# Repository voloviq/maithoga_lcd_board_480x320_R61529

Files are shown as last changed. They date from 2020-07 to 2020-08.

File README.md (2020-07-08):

# maithoga_lcd_board_480x320_R61529
PCB Board for Maithoga display with resolution 480x320 based on chip R61529 compatible with ILI9481.

Access to display signal is possible with goldpin described below and fpc compatible with LicheePi Zero board.

Display view

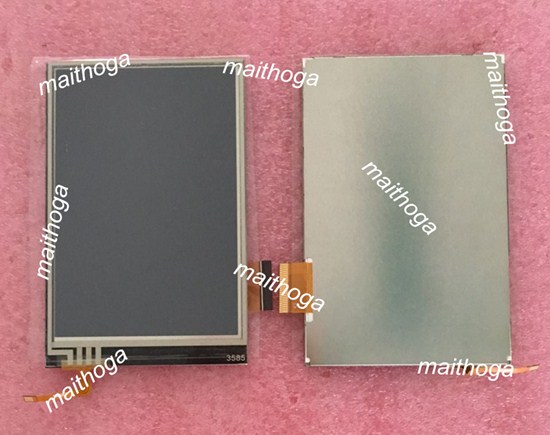
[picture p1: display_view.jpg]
Display_View


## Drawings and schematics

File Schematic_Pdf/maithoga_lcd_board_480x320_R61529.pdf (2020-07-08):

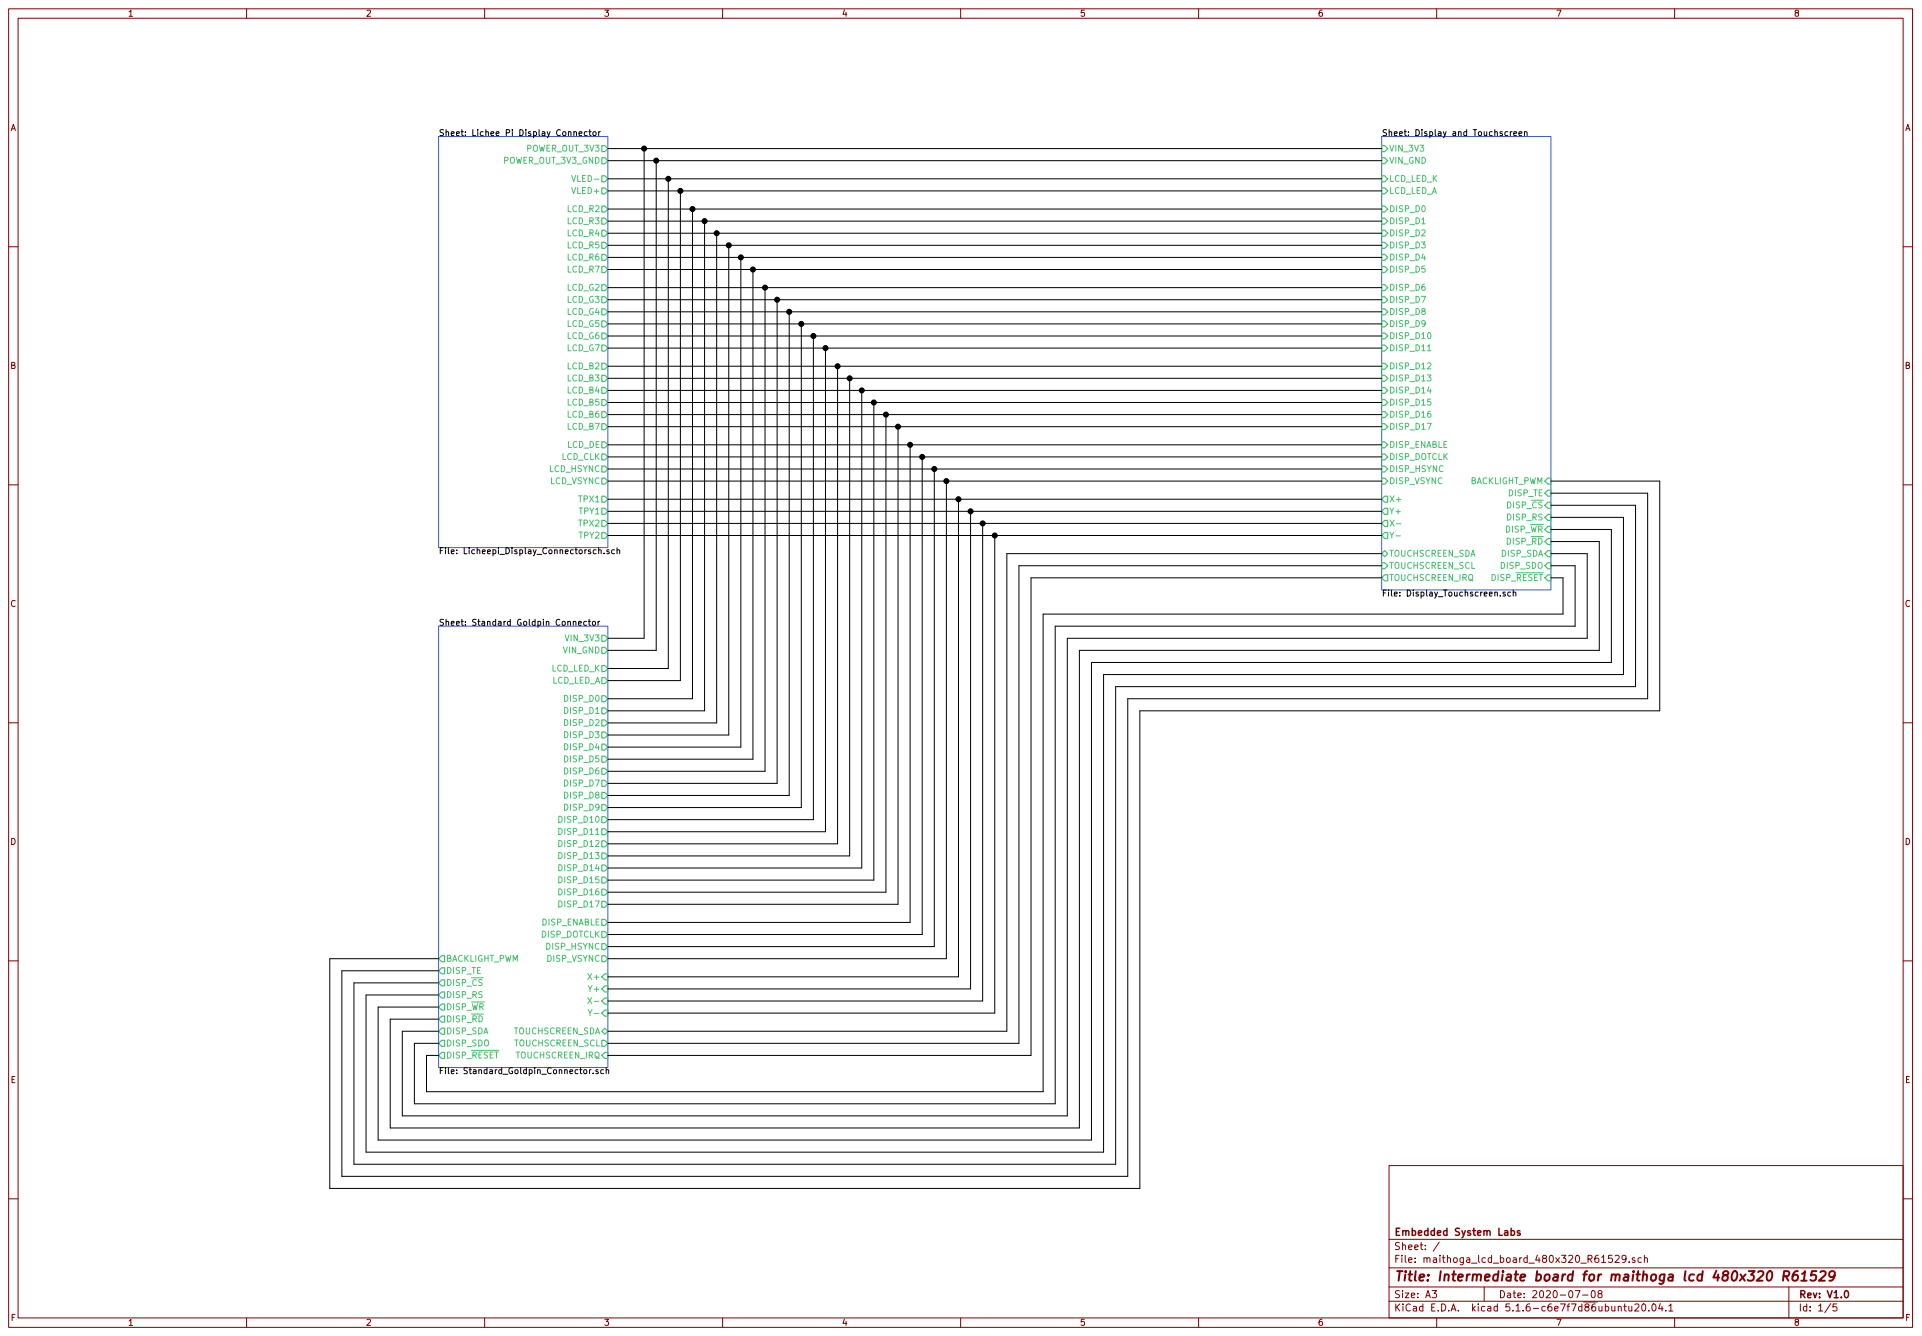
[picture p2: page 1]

File: Licheepi_Display_Connectorsch.sch VLED- VLED+

Sheet: Lichee Pi Display Connector
TPX1 TPY1 TPX2 TPY2 POWER_OUT_3V3 POWER_OUT_3V3_GND

Sheet: Standard Goldpin Connector
DISP_D0 DISP_D1 DISP_D2 DISP_D3 DISP_D4 DISP_D5 DISP_D6 DISP_D7 DISP_D8 DISP_D9 DISP_D10 DISP_D11 DISP_D12 DISP_D13 DISP_D14 DISP_D15 DISP_D16 DISP_D17 DISP_ENABLE DISP_DOTCLK DISP_HSYNC

File: maithoga_lcd_board_480x320_R61529.sch Sheet: / Embedded System Labs

Id: 1/5 Title: Intermediate board for maithoga lcd 480x320 R61529

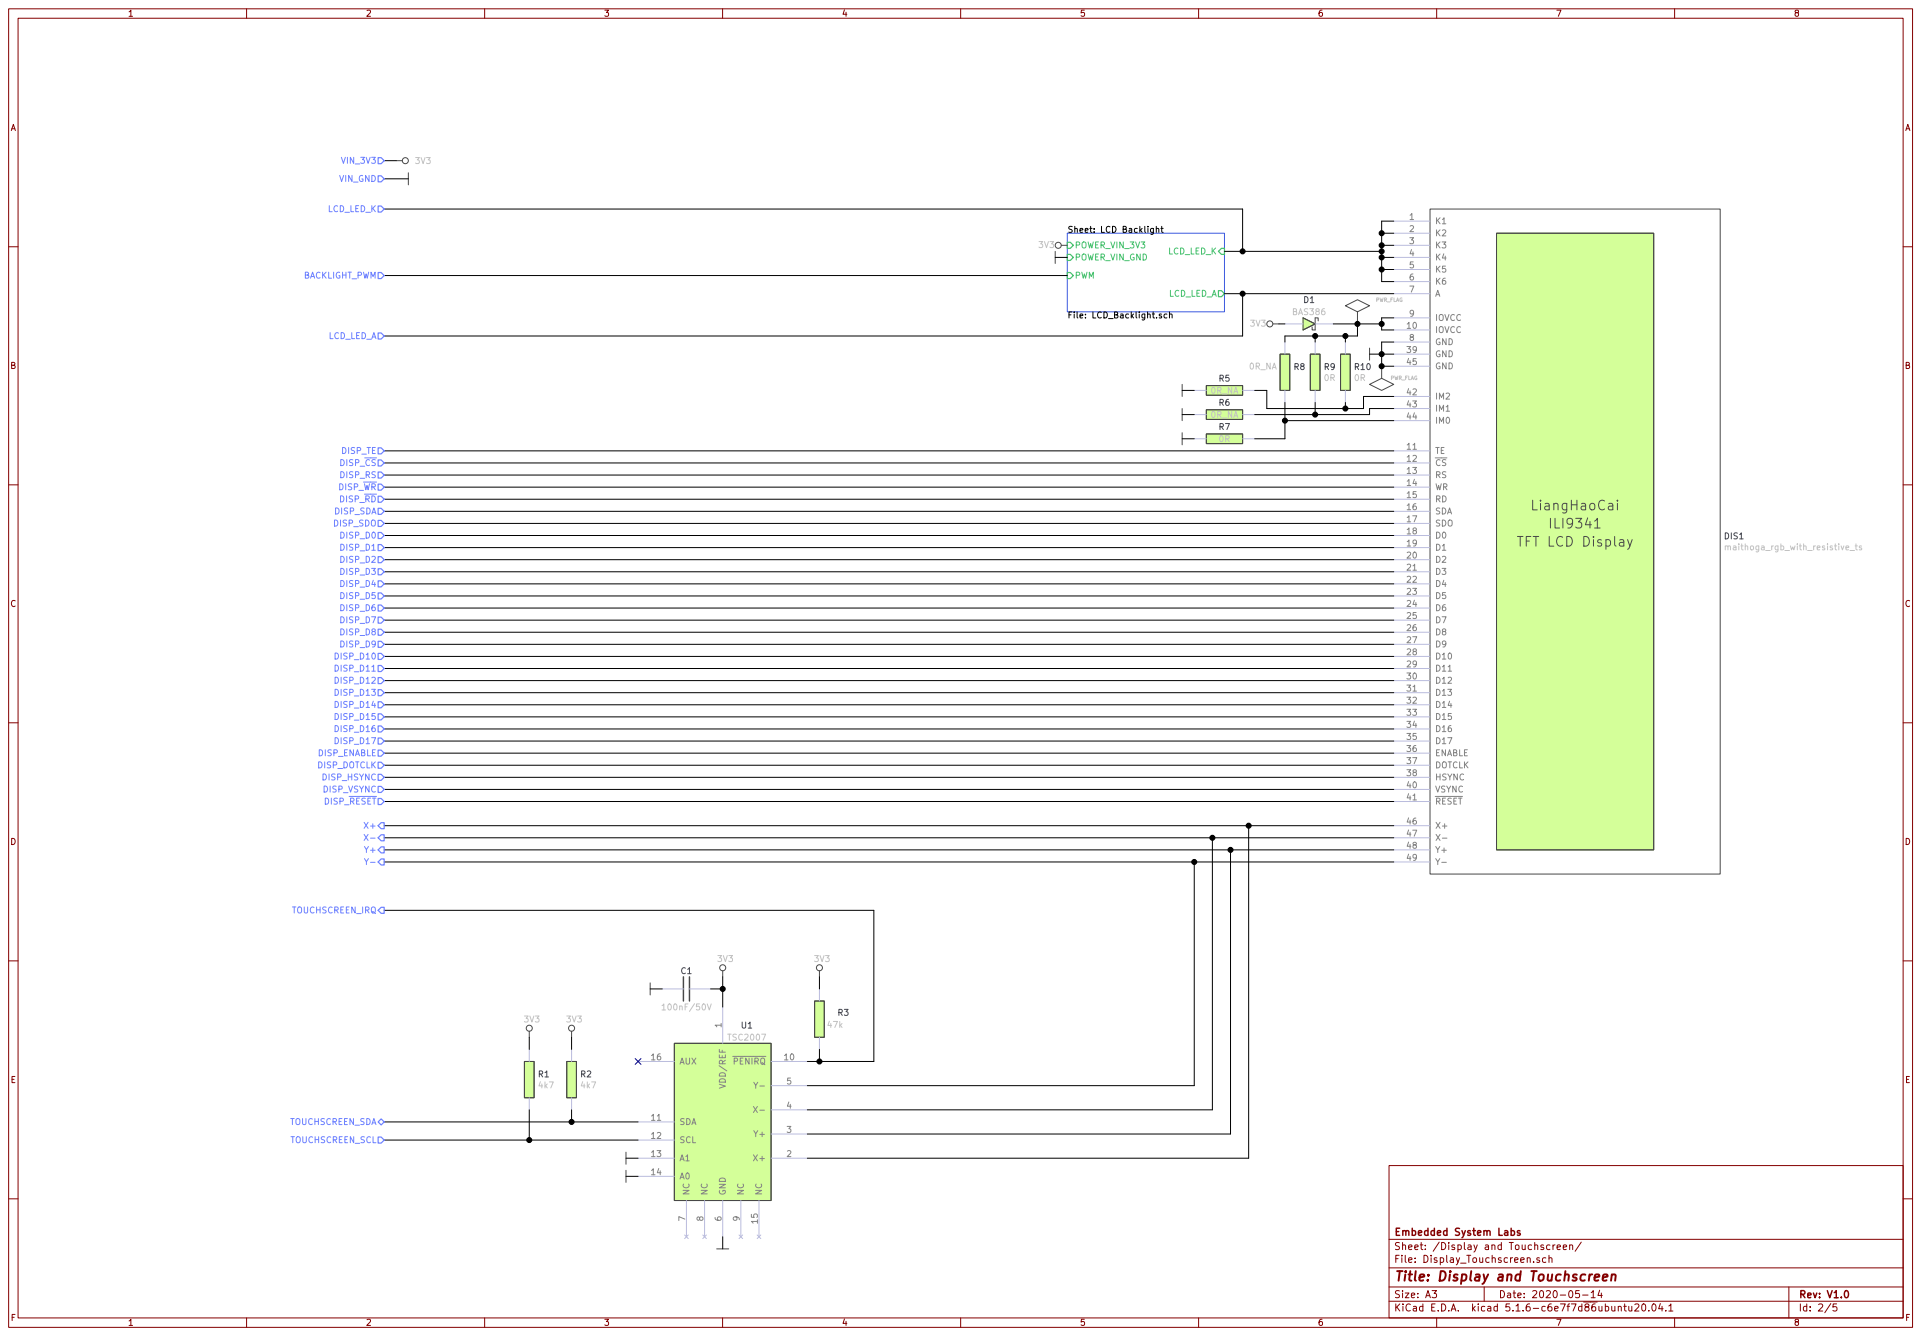
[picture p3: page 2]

Embedded System Labs
Sheet: /Display and Touchscreen/
File: Display_Touchscreen.sch
Id: 2/5 Title: Display and Touchscreen

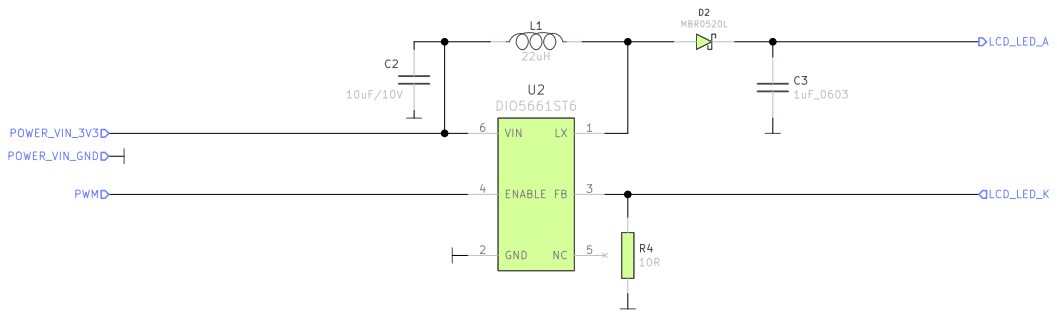
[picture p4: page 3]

Embedded System Labs
Sheet: /Display and Touchscreen/LCD Backlight/
File: LCD_Backlight.sch
Id: 3/5 Title: LCD Backlight

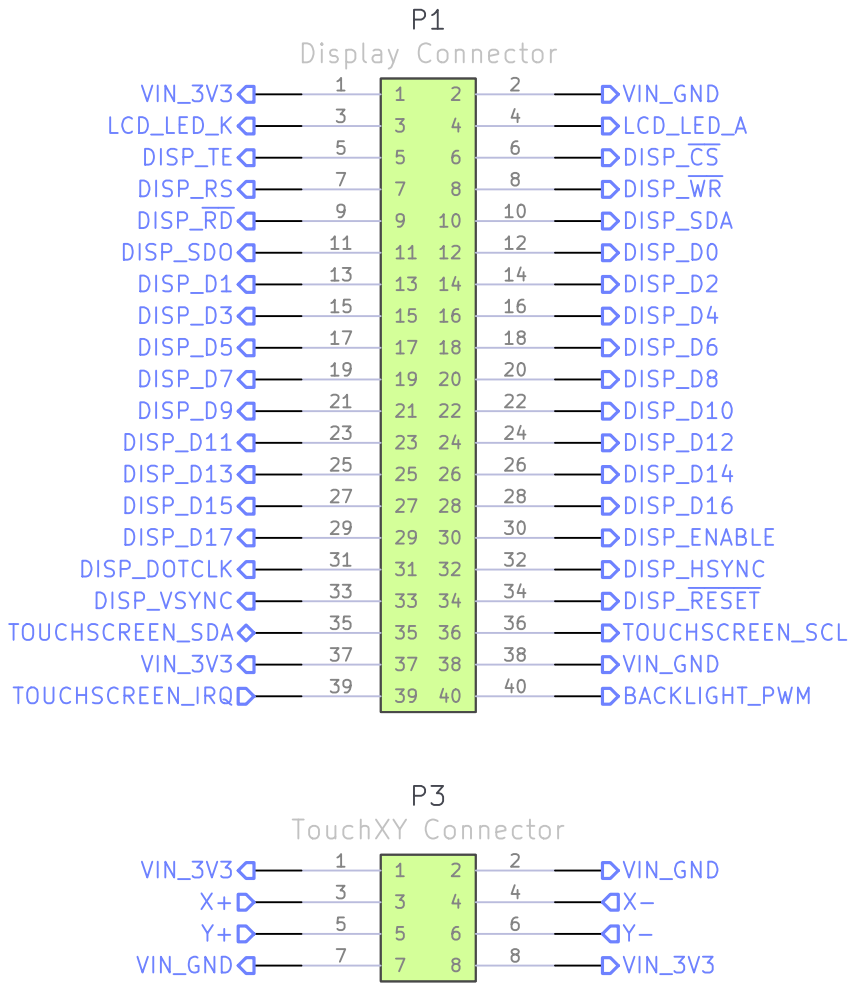
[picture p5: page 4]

Embedded System Labs
Sheet: /Standard Goldpin Connector/
File: Standard_Goldpin_Connector.sch
Id: 4/5 Title: Goldpin Display Connector

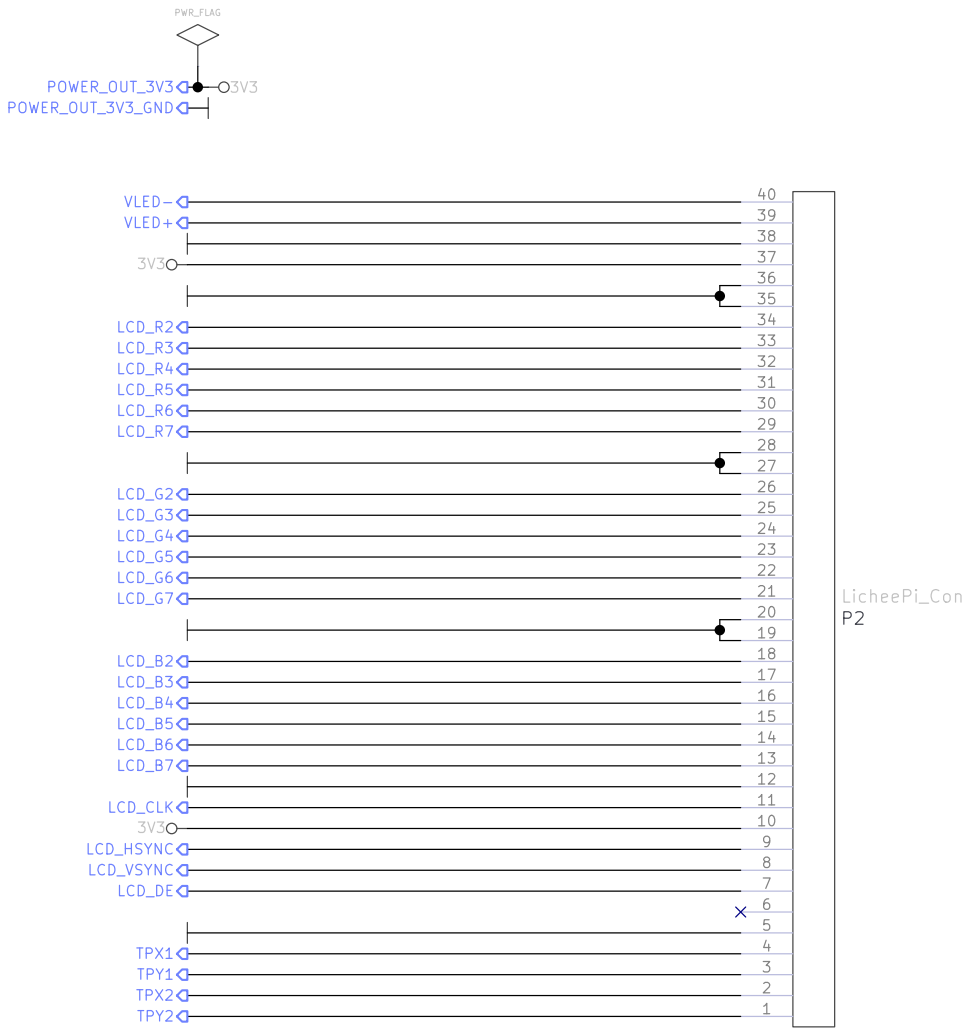
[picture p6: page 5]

Embeddes System Labs
Sheet: /Lichee Pi Display Connector/
File: Licheepi_Display_Connectorsch.sch
Id: 5/5 Title: Fpc Display Connector compatible wih Lichee Pi

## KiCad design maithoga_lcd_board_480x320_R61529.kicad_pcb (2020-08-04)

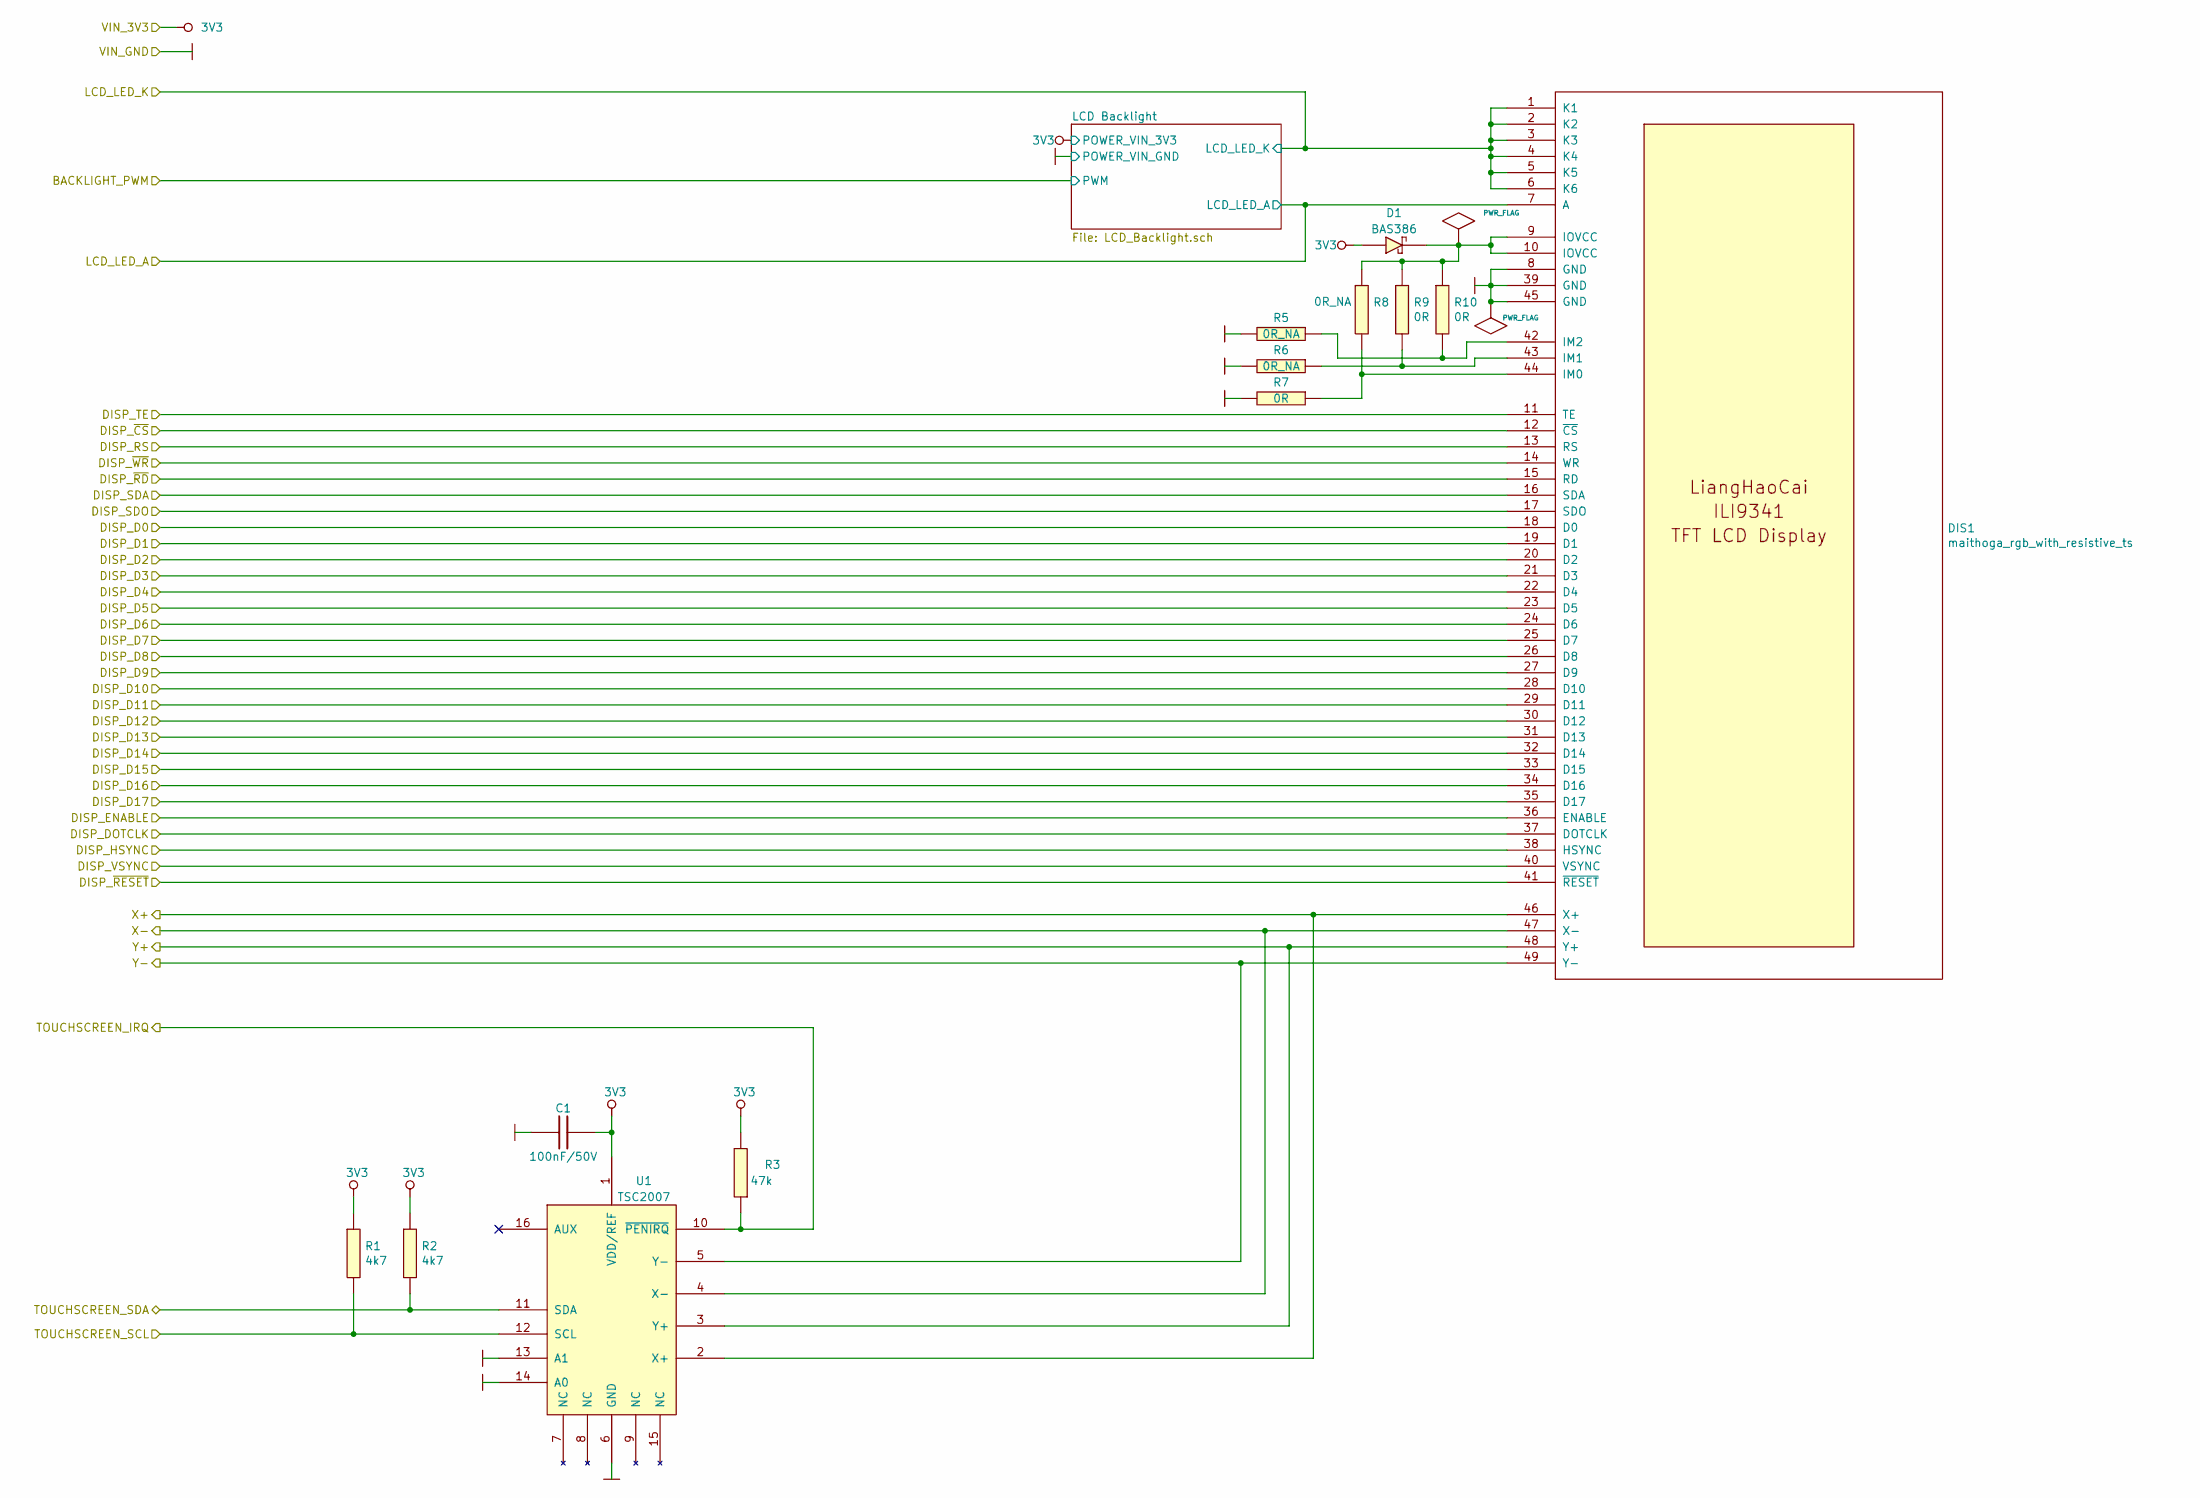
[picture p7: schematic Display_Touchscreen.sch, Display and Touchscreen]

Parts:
C1: 100nF/50V; 100nF_0603; Manufacturer Part Number CL10B104JB8NNNC
D1: BAS386; BAS386_MICROMELF
DIS1: maithoga_rgb_with_resistive_ts; maithoga_tft_480x320_rgb_with_resistive_ts
R1, R2: 4k7; 4k7_0603; Manufacturer Part Number 0603SAF4701T5E
R3: 47k; 47k_0603
R5, R6, R8: 0R_NA; 0R_0603; Manufacturer Part Number 0603SAJ0000T5E
R7, R9, R10: 0R; 0R_0603; Manufacturer Part Number 0603SAJ0000T5E
U1: TSC2007; TSC2007_TSSOP16; Manufacturer Part Number TSC2007IPWR; LCSC Part # (optional) C38398

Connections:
3V3: C1.1, D1.1 (A), R1.1, R2.1, R3.2, U1.1 (VDD/REF); also elsewhere on the board
/Display and Touchscreen/DISP_D0: DIS1.18 (D0); also elsewhere on the board
/Display and Touchscreen/DISP_D1: DIS1.19 (D1); also elsewhere on the board
/Display and Touchscreen/DISP_D2: DIS1.20 (D2); also elsewhere on the board
/Display and Touchscreen/DISP_D3: DIS1.21 (D3); also elsewhere on the board
/Display and Touchscreen/DISP_D4: DIS1.22 (D4); also elsewhere on the board
/Display and Touchscreen/DISP_D5: DIS1.23 (D5); also elsewhere on the board
/Display and Touchscreen/DISP_D6: DIS1.24 (D6); also elsewhere on the board
/Display and Touchscreen/DISP_D7: DIS1.25 (D7); also elsewhere on the board
/Display and Touchscreen/DISP_D8: DIS1.26 (D8); also elsewhere on the board
/Display and Touchscreen/DISP_D9: DIS1.27 (D9); also elsewhere on the board
/Display and Touchscreen/DISP_D10: DIS1.28 (D10); also elsewhere on the board
/Display and Touchscreen/DISP_D11: DIS1.29 (D11); also elsewhere on the board
/Display and Touchscreen/DISP_D12: DIS1.30 (D12); also elsewhere on the board
/Display and Touchscreen/DISP_D13: DIS1.31 (D13); also elsewhere on the board
/Display and Touchscreen/DISP_D14: DIS1.32 (D14); also elsewhere on the board
/Display and Touchscreen/DISP_D15: DIS1.33 (D15); also elsewhere on the board
/Display and Touchscreen/DISP_D16: DIS1.34 (D16); also elsewhere on the board
/Display and Touchscreen/DISP_D17: DIS1.35 (D17); also elsewhere on the board
/Display and Touchscreen/DISP_DOTCLK: DIS1.37 (DOTCLK); also elsewhere on the board
/Display and Touchscreen/DISP_ENABLE: DIS1.36 (ENABLE); also elsewhere on the board
/Display and Touchscreen/DISP_HSYNC: DIS1.38 (HSYNC); also elsewhere on the board
/Display and Touchscreen/DISP_RS: DIS1.13 (RS); also elsewhere on the board
/Display and Touchscreen/DISP_SDA: DIS1.16 (SDA); also elsewhere on the board
/Display and Touchscreen/DISP_SDO: DIS1.17 (SDO); also elsewhere on the board
/Display and Touchscreen/DISP_TE: DIS1.11 (TE); also elsewhere on the board
/Display and Touchscreen/DISP_VSYNC: DIS1.40 (VSYNC); also elsewhere on the board
/Display and Touchscreen/DISP_~CS~: DIS1.12 (~CS); also elsewhere on the board
/Display and Touchscreen/DISP_~RD~: DIS1.15 (RD); also elsewhere on the board
/Display and Touchscreen/DISP_~RESET~: DIS1.41 (~RESET); also elsewhere on the board
/Display and Touchscreen/DISP_~WR~: DIS1.14 (WR); also elsewhere on the board
/Display and Touchscreen/LCD_LED_A: DIS1.7 (A); also elsewhere on the board
/Display and Touchscreen/LCD_LED_K: DIS1.1 (K1), DIS1.2 (K2), DIS1.3 (K3), DIS1.4 (K4), DIS1.5 (K5), DIS1.6 (K6); also elsewhere on the board
/Display and Touchscreen/TOUCHSCREEN_IRQ: R3.1, U1.10 (~PENIRQ); also elsewhere on the board
/Display and Touchscreen/TOUCHSCREEN_SCL: R1.2, U1.12 (SCL); also elsewhere on the board
/Display and Touchscreen/TOUCHSCREEN_SDA: R2.2, U1.11 (SDA); also elsewhere on the board
/Lichee Pi Display Connector/TPX1: DIS1.46 (X+), U1.2 (X+); also elsewhere on the board
/Lichee Pi Display Connector/TPX2: DIS1.47 (X-), U1.4 (X-); also elsewhere on the board
/Lichee Pi Display Connector/TPY1: DIS1.48 (Y+), U1.3 (Y+); also elsewhere on the board
/Lichee Pi Display Connector/TPY2: DIS1.49 (Y-), U1.5 (Y-); also elsewhere on the board
GND: C1.2, DIS1.8 (GND), DIS1.39 (GND), DIS1.45 (GND), R5.2, R6.2, R7.2, U1.6 (GND), U1.13 (A1), U1.14 (A0); also elsewhere on the board
unnamed: D1.2 (K), DIS1.9 (IOVCC), DIS1.10 (IOVCC), R8.1, R9.1, R10.1
unnamed: DIS1.42 (IM2), R5.1, R10.2
unnamed: DIS1.43 (IM1), R6.1, R9.2
unnamed: DIS1.44 (IM0), R7.1, R8.2

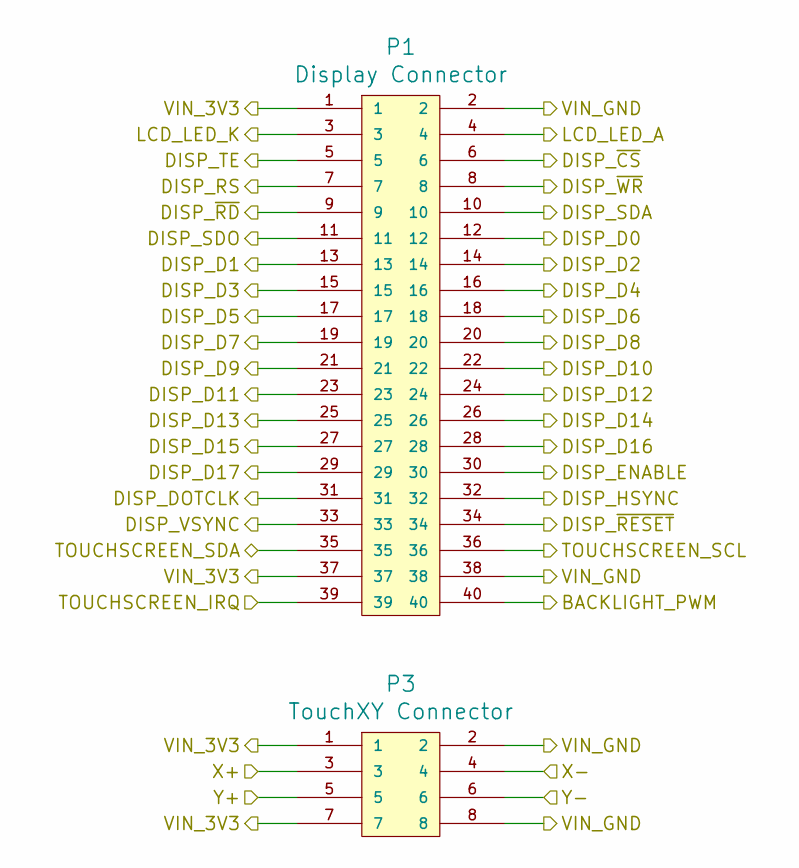
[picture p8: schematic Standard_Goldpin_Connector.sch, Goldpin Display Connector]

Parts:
P1: Display Connector; Goldpin_20_2_2_54mm_SMT
P3: TouchXY Connector; Goldpin_4_2_2_54mm_SMT

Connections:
3V3: P1.1, P1.37, P3.1, P3.7; also elsewhere on the board
/Display and Touchscreen/BACKLIGHT_PWM: P1.40; also elsewhere on the board
/Display and Touchscreen/DISP_D0: P1.12; also elsewhere on the board
/Display and Touchscreen/DISP_D1: P1.13; also elsewhere on the board
/Display and Touchscreen/DISP_D2: P1.14; also elsewhere on the board
/Display and Touchscreen/DISP_D3: P1.15; also elsewhere on the board
/Display and Touchscreen/DISP_D4: P1.16; also elsewhere on the board
/Display and Touchscreen/DISP_D5: P1.17; also elsewhere on the board
/Display and Touchscreen/DISP_D6: P1.18; also elsewhere on the board
/Display and Touchscreen/DISP_D7: P1.19; also elsewhere on the board
/Display and Touchscreen/DISP_D8: P1.20; also elsewhere on the board
/Display and Touchscreen/DISP_D9: P1.21; also elsewhere on the board
/Display and Touchscreen/DISP_D10: P1.22; also elsewhere on the board
/Display and Touchscreen/DISP_D11: P1.23; also elsewhere on the board
/Display and Touchscreen/DISP_D12: P1.24; also elsewhere on the board
/Display and Touchscreen/DISP_D13: P1.25; also elsewhere on the board
/Display and Touchscreen/DISP_D14: P1.26; also elsewhere on the board
/Display and Touchscreen/DISP_D15: P1.27; also elsewhere on the board
/Display and Touchscreen/DISP_D16: P1.28; also elsewhere on the board
/Display and Touchscreen/DISP_D17: P1.29; also elsewhere on the board
/Display and Touchscreen/DISP_DOTCLK: P1.31; also elsewhere on the board
/Display and Touchscreen/DISP_ENABLE: P1.30; also elsewhere on the board
/Display and Touchscreen/DISP_HSYNC: P1.32; also elsewhere on the board
/Display and Touchscreen/DISP_RS: P1.7; also elsewhere on the board
/Display and Touchscreen/DISP_SDA: P1.10; also elsewhere on the board
/Display and Touchscreen/DISP_SDO: P1.11; also elsewhere on the board
/Display and Touchscreen/DISP_TE: P1.5; also elsewhere on the board
/Display and Touchscreen/DISP_VSYNC: P1.33; also elsewhere on the board
/Display and Touchscreen/DISP_~CS~: P1.6; also elsewhere on the board
/Display and Touchscreen/DISP_~RD~: P1.9; also elsewhere on the board
/Display and Touchscreen/DISP_~RESET~: P1.34; also elsewhere on the board
/Display and Touchscreen/DISP_~WR~: P1.8; also elsewhere on the board
/Display and Touchscreen/LCD_LED_A: P1.4; also elsewhere on the board
/Display and Touchscreen/LCD_LED_K: P1.3; also elsewhere on the board
/Display and Touchscreen/TOUCHSCREEN_IRQ: P1.39; also elsewhere on the board
/Display and Touchscreen/TOUCHSCREEN_SCL: P1.36; also elsewhere on the board
/Display and Touchscreen/TOUCHSCREEN_SDA: P1.35; also elsewhere on the board
/Lichee Pi Display Connector/TPX1: P3.3; also elsewhere on the board
/Lichee Pi Display Connector/TPX2: P3.4; also elsewhere on the board
/Lichee Pi Display Connector/TPY1: P3.5; also elsewhere on the board
/Lichee Pi Display Connector/TPY2: P3.6; also elsewhere on the board
GND: P1.2, P1.38, P3.2, P3.8; also elsewhere on the board

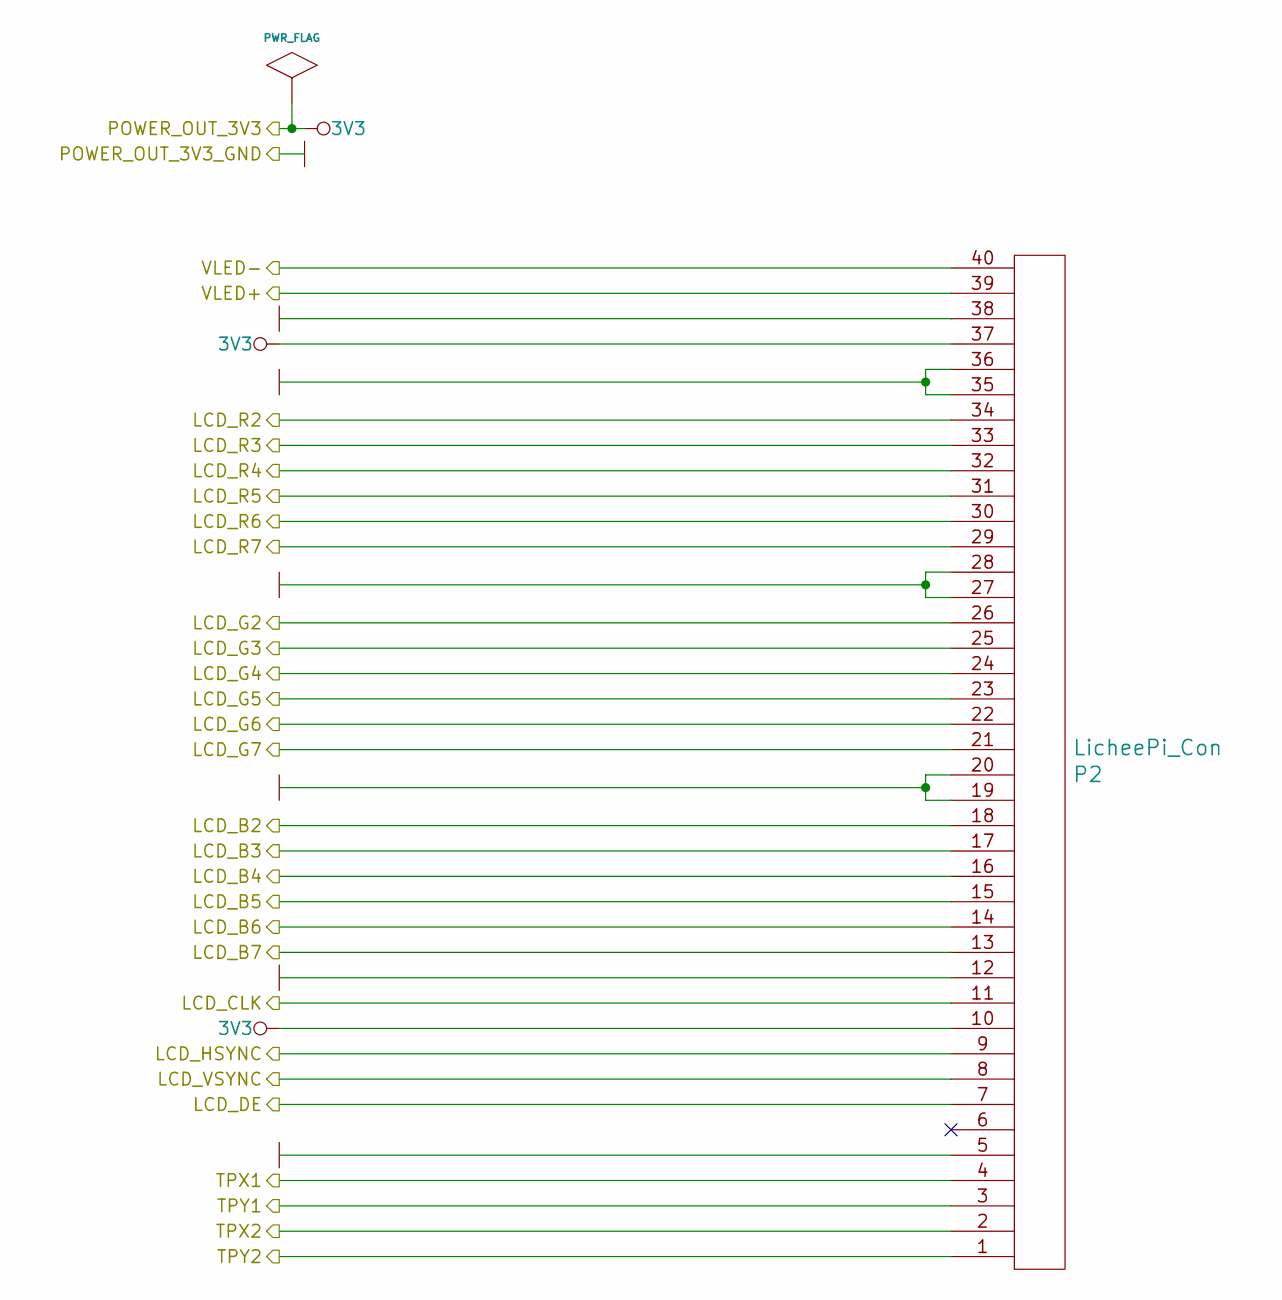
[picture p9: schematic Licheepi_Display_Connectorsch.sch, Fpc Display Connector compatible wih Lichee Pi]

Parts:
P2: LicheePi_Con; 40pin_fpc_top_0_5mm

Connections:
3V3: P2.10, P2.37 (P7); also elsewhere on the board
/Display and Touchscreen/DISP_D0: P2.34 (P4); also elsewhere on the board
/Display and Touchscreen/DISP_D1: P2.33 (P3); also elsewhere on the board
/Display and Touchscreen/DISP_D2: P2.32 (P2); also elsewhere on the board
/Display and Touchscreen/DISP_D3: P2.31 (P1); also elsewhere on the board
/Display and Touchscreen/DISP_D4: P2.30 (P10); also elsewhere on the board
/Display and Touchscreen/DISP_D5: P2.29 (P9); also elsewhere on the board
/Display and Touchscreen/DISP_D6: P2.26 (P6); also elsewhere on the board
/Display and Touchscreen/DISP_D7: P2.25 (P5); also elsewhere on the board
/Display and Touchscreen/DISP_D8: P2.24 (P4); also elsewhere on the board
/Display and Touchscreen/DISP_D9: P2.23 (P3); also elsewhere on the board
/Display and Touchscreen/DISP_D10: P2.22 (P2); also elsewhere on the board
/Display and Touchscreen/DISP_D11: P2.21 (P1); also elsewhere on the board
/Display and Touchscreen/DISP_D12: P2.18 (P8); also elsewhere on the board
/Display and Touchscreen/DISP_D13: P2.17 (P7); also elsewhere on the board
/Display and Touchscreen/DISP_D14: P2.16 (P6); also elsewhere on the board
/Display and Touchscreen/DISP_D15: P2.15 (P5); also elsewhere on the board
/Display and Touchscreen/DISP_D16: P2.14 (P4); also elsewhere on the board
/Display and Touchscreen/DISP_D17: P2.13 (P3); also elsewhere on the board
/Display and Touchscreen/DISP_DOTCLK: P2.11 (P1); also elsewhere on the board
/Display and Touchscreen/DISP_ENABLE: P2.7; also elsewhere on the board
/Display and Touchscreen/DISP_HSYNC: P2.9; also elsewhere on the board
/Display and Touchscreen/DISP_VSYNC: P2.8; also elsewhere on the board
/Display and Touchscreen/LCD_LED_A: P2.39 (P9); also elsewhere on the board
/Display and Touchscreen/LCD_LED_K: P2.40 (P10); also elsewhere on the board
/Lichee Pi Display Connector/TPX1: P2.4; also elsewhere on the board
/Lichee Pi Display Connector/TPX2: P2.2; also elsewhere on the board
/Lichee Pi Display Connector/TPY1: P2.3; also elsewhere on the board
/Lichee Pi Display Connector/TPY2: P2.1; also elsewhere on the board
GND: P2.5, P2.12 (P2), P2.19 (P9), P2.20 (P10), P2.27 (P7), P2.28 (P8), P2.35 (P5), P2.36 (P6), P2.38 (P8); also elsewhere on the board

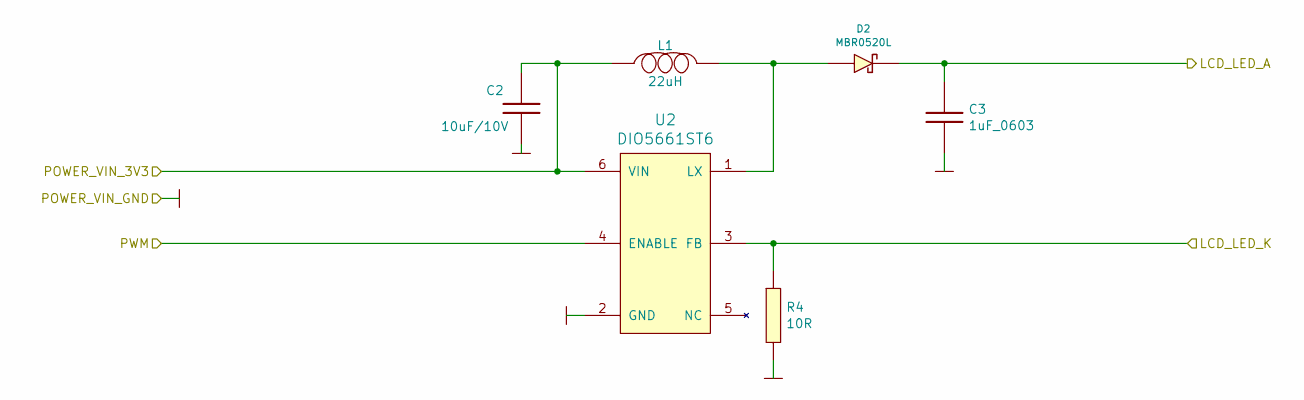
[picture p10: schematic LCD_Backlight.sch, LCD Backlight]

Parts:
C2: 10uF/10V; 10uF_10V_0603; Manufacturer Part Number C0603C106M9PACTU; LCSC Part # (optional) C162265
C3: 1uF_0603; Manufacturer Part Number CL10B105KO8NNNC
D2: MBR0520L; MBR0520L_SOD123
L1: 22uH; 22uH_2520; Manufacturer Part Number Murata Electronics; LCSC Part # (optional) C375967
R4: 10R; 10R_0603
U2: DIO5661ST6; Manufacturer Part Number DIO5661ST6; LCSC Part # (optional) C324576

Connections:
3V3: C2.2, L1.1, U2.6 (VIN); also elsewhere on the board
/Display and Touchscreen/BACKLIGHT_PWM: U2.4 (ENABLE); also elsewhere on the board
/Display and Touchscreen/LCD_LED_A: C3.1, D2.1 (K); also elsewhere on the board
/Display and Touchscreen/LCD_LED_K: R4.1, U2.3 (FB); also elsewhere on the board
GND: C2.1, C3.2, R4.2, U2.2 (GND); also elsewhere on the board
unnamed: D2.2 (A), L1.2, U2.1 (LX)

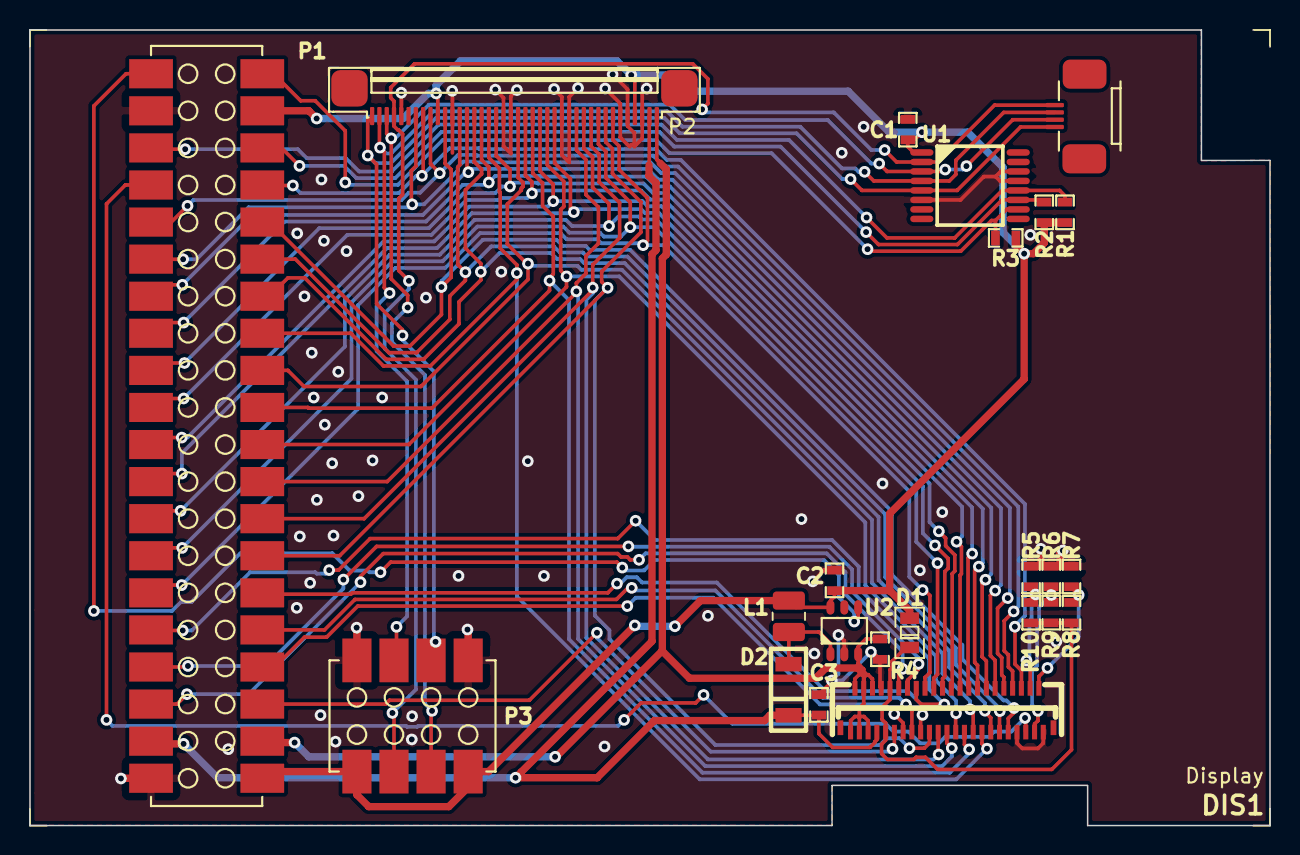
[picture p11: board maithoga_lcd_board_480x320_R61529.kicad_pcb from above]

Board: 2 copper layers, 85.0 x 54.5 mm, 22 parts (0 on the bottom side), 47 nets.

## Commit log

2020-07-08 Schematic in progress
    [Display_Touchscreen.sch, LCD_Backlight.sch, Licheepi_Display_Connectorsch.sch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]
2020-07-08 Filled hierarchical sheets
    [Display_Touchscreen.sch, Licheepi_Display_Connectorsch.sch, Standard_Goldpin_Connector.sch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]
2020-07-08 Schematic ready, need check
    [Display_Touchscreen.sch, Licheepi_Display_Connectorsch.sch, Standard_Goldpin_Connector.sch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]
2020-07-08 Schematic finished, pcb tracking started
    [Licheepi_Display_Connectorsch.sch, maithoga_lcd_board_480x320_R61529.kicad_pcb]
2020-07-08 Added resistor mode select on schematic
    [Display_Touchscreen.sch, maithoga_lcd_board_480x320_R61529.kicad_pcb]
2020-07-09 Added outline on pcb
    [maithoga_lcd_board_480x320_R61529.kicad_pcb]
2020-07-09 Tracking in progress
    [Standard_Goldpin_Connector.sch, maithoga_lcd_board_480x320_R61529.kicad_pcb]
2020-08-04 Tracking finished
    [maithoga_lcd_board_480x320_R61529.kicad_pcb]
2020-08-04 Generated gerbers
    [maithoga_lcd_board_480x320_R61529-B_Cu.gbr, maithoga_lcd_board_480x320_R61529-B_Mask.gbr, maithoga_lcd_board_480x320_R61529-B_Paste.gbr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]
